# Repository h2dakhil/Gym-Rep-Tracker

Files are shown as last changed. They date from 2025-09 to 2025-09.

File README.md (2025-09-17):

# Fitness Rep Tracker 🏋️‍♂️

A **wrist-mounted STM32 wearable** that detects and classifies **4+ gym exercises** with real-time feedback.  
The project was built completely from scratch, including **custom 4-layer PCB design, embedded firmware, IMU motion sensing, and OLED feedback display.**

---

## 🚀 Features
- **Hardware**
  - Custom **4-layer PCB** designed in KiCad
  - MCU: **STM32F103**
  - IMU: **MPU-6050** (3-axis accelerometer + 3-axis gyroscope, I²C)
  - Display: **SSD1306 OLED** (128×64, I²C)
  - Power: **MCP73831 Li-ion charger**, 3.3 V LDO, battery-sense divider, USB-C input
  - Debug: **SWD header**, status LEDs

- **Firmware (C)**
  - Written in **C** using **PlatformIO** and STM32 HAL drivers
  - **IMU data acquisition** and calibration
  - **Rep detection algorithm** using peak prominence + refractory period filtering
  - Rolling buffer statistics & low-pass signal filters
  - State machine: boot → exercise selection → calibration → running
  - **OLED driver** for real-time rep count & status display
  - UART logging for debugging
  - Peripheral initialization with fallback & error handling

- **Testing & Debugging**
  - SMT soldered & validated using **DMM** and **oscilloscope**
  - Verified stable 3.3 V rail and signal nets

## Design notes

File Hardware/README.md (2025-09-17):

# Gym Rep Tracker Hardware

This directory contains the **hardware design files** for the Gym Rep Tracker, including schematics, PCB layouts, fabrication outputs, and backups.  
The hardware is built around the **STM32F103CBT6 microcontroller**, with supporting circuitry for the **MPU-6050 IMU**, **SSD1306 OLED**, battery charging, and power regulation.

---

## Directory Structure

- **Backups/**  
  Contains backup copies of hardware design files for recovery and version tracking.  

- **Fab/**  
  Fabrication-ready outputs, including Gerber files, drill files, and pick-and-place exports for PCB manufacturing.  

- **PCB/**  
  Source PCB design files (e.g., KiCad project files, layout, footprints).  
  - Includes board layout for the 4-layer stack-up (GND plane, power plane, signal layers).  

- **Schematic/**  
  Electrical schematics showing MCU, IMU, OLED, power management (MCP73831 Li-ion charger, LDO regulator), and supporting passives.  

- **README.md**  
  This file, describing the structure and usage of the hardware directory.  

---

## Usage

1. **View Schematics**  
   Open the files in the `Schematic/` folder using KiCad (recommended version noted in project files).  

2. **Edit PCB Layout**  
   Open the project in KiCad from the `PCB/` folder.  

3. **Generate Manufacturing Files**  
   Use KiCad’s *Plot* and *Fabrication Outputs* to regenerate Gerbers if changes are made.  
   Fabrication-ready files are already available in the `Fab/` folder.  

---

## Notes
- **Backups** are not guaranteed to be the latest version. Always check the active `PCB/` and `Schematic/` folders first.  
- Ensure fabrication files match the correct **4-layer stack-up** before sending to a manufacturer.  
- If modifying, confirm footprints and net connections pass ERC/DRC in KiCad before fabrication.

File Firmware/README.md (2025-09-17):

# Gym Rep Tracker Firmware

This directory contains the embedded firmware for a wrist-mounted rep tracker built around an **STM32F103CBT6 microcontroller**, **MPU-6050 IMU**, and **SSD1306 OLED display**.  
The firmware implements sensor drivers, signal filtering, calibration, and a rep-detection algorithm tailored to multiple exercises.

---

## Features
- **Multi-Exercise Support**: Bicep Curl, Shoulder Press, Bench Press (extendable to more)
- **State Machine Control**: Boot → Exercise Selection → Calibration → Detecting → Running
- **Exercise-Specific Calibration**: Per-exercise baseline mean/std. deviation, with dynamic thresholds
- **Rep Detection Algorithm**: Peak detection with prominence & refractory checks to prevent false counts
- **Low-Pass Filtering**: Smooths accelerometer/gyroscope signals for robust detection
- **OLED UI**: Displays splash, exercise selection, calibration state, rep counts, and status messages
- **UART Debug Logging (optional)**: Real-time streaming of thresholds, IMU samples, and rep detection results
- **Fallback Protection**: I²C bus initialization with automatic downgrade from fast to standard mode if needed

---

## Build & Flash Instructions
1. **Install PlatformIO**: Install the PlatformIO extension in VS Code.  
2. **Open Project**: Open the `Firmware/` directory.  
3. **Build**:  
   platformio run

or click the Build checkmark in the toolbar.

4. Flash: Upload to STM32F103CBT6 via ST-Link:

# Wiring Summary
- **MCU**: STM32F103CBT6  
- **IMU (MPU-6050) & OLED (SSD1306)**: Shared I²C1 bus  
  - PB6 → I2C1_SCL  
  - PB7 → I2C1_SDA  
  - Ensure 3.3 V supply and pull-ups (≈4.7kΩ) on SDA/SCL if not onboard  
- **Optional UART Logging**:  
  - PA2 → TX  
  - PA3 → RX  

---

# Firmware Architecture

## Drivers
- **mpu6050.c**: Initializes sensor, configures DLPF, handles calibration, scaling raw IMU data  
- **ssd1306.c**: Minimal OLED driver with ASCII rendering and UI helpers  
- **i2c_bus.c**: HAL wrapper for I²C; includes fallback from Fast Mode to Standard Mode  

## Core Logic
- **imu_filters.c**: Applies low-pass filters, projects motion onto exercise-specific axes  
- **rep_detect.c**: Maintains rolling mean/std. deviation buffer; detects peaks using thresholds  
- **app_controller.c**: High-level state machine managing boot, calibration, detection, and UI updates  
- **systick.c**: Millisecond tick counter for scheduling  

## UI
- Displays splash, exercise name, calibration, live rep counts  
- Text rendering with auto-centering and truncation  

---

# Adding a New Exercise
1. Add a new entry in `include/exercise_config.h` with thresholds & refractory time.  
2. Implement signal projection in `imu_filters.c`.  
3. Update `app_controller.c` for name display and calibration needs.  
4. Test & tune thresholds using UART logging.  

---

# Debug & Troubleshooting

## Enable Debug Mode
- Define `ENABLE_LOG_UART` in `app_config.h` to stream real-time values at **115200 baud**.  

## Common Issues
- **No reps detected** → lower `thresh_k` or `min_prominence_g`  
- **False positives** → increase `min_prominence_g` or `refractory_ms`  
- **IMU not responding** → check I²C wiring & power  
- **Display issues** → confirm pull-ups on SDA/SCL

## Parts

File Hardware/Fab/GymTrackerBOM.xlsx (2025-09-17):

BOM: Gym Rep Tracker Device
Haya Dakhil
Designator | Description | Quantity | Value | Package/ Footprint | Manufacturer Part Number (MPN) | Supplier | Supplier part number | Link
J1 | Battery Connector | 1 |  | JST_PH_S2B-PH-SM4-TB_1x02-1MP_P2.00mm_Horizontal | S2B-PH-SM4-TB(LF)(SN) | LCSC | C295747 | https://www.lcsc.com/product-detail/C295747.html?s_z=n_JST%20S2B-PH-SM4-TB%28LF%29%28SN%29
J2 | Female OLED Conn | 1 |  | Connector_PinSocket_2.54mm:PinSocket_1x04_P2.54mm_Vertical | BOOMELE(Boom Precision Elec) 2.54-1*4P | LCSC | C2718488 | https://www.lcsc.com/product-detail/C2718488.html
DNP | Male OLED Pin | 1 |  |  | B-2100S04P-A110 | LCSC | C124378 | https://www.lcsc.com/product-detail/C124378.html?s_z=n_C124378
DNP | OLED Display | 1 |  |  | HS91L02W2C01 | LCSC | C5248081 | https://www.lcsc.com/product-detail/C5248081.html?s_z=n_C5248081
DNP | IMU Breakout Board | 1 |  |  |  | Amazon |  | https://www.amazon.ca/Acceleration-Sensors-Accelerometer-Three-Axis-Quadcopter/dp/B0C3LG1Y6W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
J3 | Female IMU Connector | 1 |  | Connector_PinSocket_2.54mm:PinSocket_1x08_P2.54mm_Vertical | 2.54-1*8P | LCSC | C27438 | https://www.lcsc.com/product-detail/C27438.html?s_z=n_1x8%25202.54mm
J4 | USBC Connector | 1 |  | Connector_USB:USB_C_Receptacle_HRO_TYPE-C-31-M-12 | TYPE-C-31-M-12 | LCSC | C165948 | https://www.lcsc.com/product-detail/C165948.html
J5 | SWD Header | 1 |  | Connector_PinHeader_2.54mm:PinHeader_1x05_P2.54mm_Vertical | PH2.54-1X5P-H25 | LCSC | C42431835 | https://www.lcsc.com/product-detail/C42431835.html?s_z=n_1x5%25202.54mm%2520pitch
DNP | SWD Linker | 1 |  |  |  |  |  | https://www.amazon.ca/DAOKAI-Downloader-Programmer-STM8STM32-Programming/dp/B09WVQNFNM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
DNP | Adapter USB-A to C | 1 |  |  |  |  |  | https://www.amazon.ca/Female-Adapter-Charger-Airpods-Samsung/dp/B083GMF4PR?sp_csd=d2lkZ2V0TmFtZT1zcF9hdGY
DNP | Battery | 1 |  |  |  |  |  | https://www.amazon.ca/FITHOOD-Rechargeable-Connector-Household-Appliances/dp/B0CYGN1627
U1 | PMIC | 1 |  | Package_TO_SOT_SMD:SOT-23-5 MIC5504-3.3YM5-TR | MCP73831T-2ACI/OT | LCSC | C424093 | https://www.lcsc.com/product-detail/C424093.html?s_z=n_C424093
U2 | LDO | 1 |  | Package_TO_SOT_SMD:SOT-23-5 | MIC5504-3.3YM5-TR | LCSC | C88419 | https://www.lcsc.com/product-detail/C88419.html?s_z=n_C88419
U3 | STM32 MCU | 1 |  | Package_QFP:LQFP-48_7x7mm_P0.5mm | STM32F103C8T6 | LCSC | C8734 | https://www.lcsc.com/product-detail/C8734.html?s_z=n_STM32F103C8T6
D1, D3 | Green LED | 2 |  | LED_SMD:LED_0603_1608Metric_Pad1.05x0.95mm_HandSolder | A-SP192DGHC-C01-4T | LCSC | C19171301 | https://www.lcsc.com/product-detail/C19171301.html?s_z=n_green%20led
D2 | TVS Diode | 1 |  | Diode_SMD:D_SMF | SMF5.0A | LCSC | C151296 | https://www.lcsc.com/product-detail/C151296.html?s_z=n_SMF5.0A
D4 | Yellow LED | 1 |  | LED_SMD:LED_0603_1608Metric_Pad1.05x0.95mm_HandSolder | XL-1608UYC-06 | LCSC | C965802 | https://www.lcsc.com/product-detail/C965802.html?s_z=n_yellow%20led
FB1 | Ferrite Bead | 1 |  | Resistor_SMD:R_0603_1608Metric | BLM18PG121SN1D | LCSC | C14709 | https://www.lcsc.com/product-detail/C14709.html?s_z=n_ferrite%2520bead
R1, R6 |  | 2 | 5.1k | Resistor_SMD:R_0603_1608Metric | RC0603FR-075K1L | LCSC | C105580 | https://www.lcsc.com/product-detail/C105580.html?s_z=n_5.1k%2520r
R2 |  | 1 | 470 | Resistor_SMD:R_0603_1608Metric | RC0603FR-07470RL | LCSC | C114669 | https://www.lcsc.com/product-detail/C114669.html?s_z=n_470%2520ohm%2520r
R3 |  | 1 | 2.0k | Resistor_SMD:R_0603_1608Metric | FRC0603J202 TS | LCSC | C2907137 | https://www.lcsc.com/product-detail/C2907137.html?s_z=n_2k%2520resistor%2520
R4, R5 |  | 2 | 10k | Resistor_SMD:R_0603_1608Metric | RC0603FR-0710KL | LCSC | C98220 | https://www.lcsc.com/product-detail/C98220.html?s_z=n_10k%2520resistor
R7, R8 |  | 2 | 1k | Resistor_SMD:R_0603_1608Metric | RC0603FR-071KL | LCSC | C22548 | https://www.lcsc.com/product-detail/C22548.html?s_z=n_1kohm%2520resistor
R9 |  | 1 | 100k | Resistor_SMD:R_0603_1608Metric | RC0603FR-07100KL | LCSC | C14675 | https://www.lcsc.com/product-detail/C14675.html?s_z=n_100kohm%2520resistor
R10 |  | 1 | 240k | Resistor_SMD:R_1206_3216Metric | FRC1206F2403TS | LCSC | C2907378 | https://www.lcsc.com/product-detail/C2907378.html?s_z=n_240kohm%2520resistor
C1 |  | 1 | 10uF | Capacitor_SMD:C_0805_2012Metric_Pad1.18x1.45mm_HandSolder | 0805X5R106K500NT | LCSC | C48579582 | https://www.lcsc.com/product-detail/C48579582.html?s_z=n_10uF%2520capacitor
C2, C3, C4, C10, C12 |  | 5 | 4.7uF | Capacitor_SMD:C_0603_1608Metric | CC0603KRX5R6BB475 | LCSC | C109456 | https://www.lcsc.com/product-detail/C109456.html?s_z=n_4.7uf%2520capacitor%2520yageo
C5, C6 |  | 2 | 1uF | Capacitor_SMD:C_0603_1608Metric_Pad1.08x0.95mm_HandSolder | CC0603KRX7R9BB105 | LCSC | C559769 | https://www.lcsc.com/product-detail/C559769.html?s_z=n_1uF%2520capacitor%2520yageo
C7, C8, C9, C11, C13, C14, C15, C16, C17 |  | 9 | 0.1uF | Capacitor_SMD:C_0603_1608Metric_Pad1.08x0.95mm_HandSolder |  | LCSC | C14663 | https://www.lcsc.com/product-detail/C14663.html?s_z=n_0.1uF%2520capacitor
SW1 | Start Button | 1 |  | Button_Switch_SMD:SW_SPST_TL3305A | TS-1187A-C-E-B | LCSC | C318887 | https://www.lcsc.com/product-detail/C318887.html
 | Helping hands |  |  |  |  |  |  | https://www.amazon.ca/STANZ-Magnifying-Selected-Soldering-Electronics/dp/B016C8RWQI
 | Flux |  |  |  |  |  |  | https://www.amazon.ca/TOWOT-Rosin-Solder-Paste-Soldering/dp/B0CNVM1KRT?sp_csd=d2lkZ2V0TmFtZT1zcF9hdGY
 | Wick |  |  |  |  |  |  | https://www.amazon.ca/Solder-TOWOT-Desoldering-Wicks-SW-2530/dp/B0943PDCC4?sp_csd=d2lkZ2V0TmFtZT1zcF9hdGY

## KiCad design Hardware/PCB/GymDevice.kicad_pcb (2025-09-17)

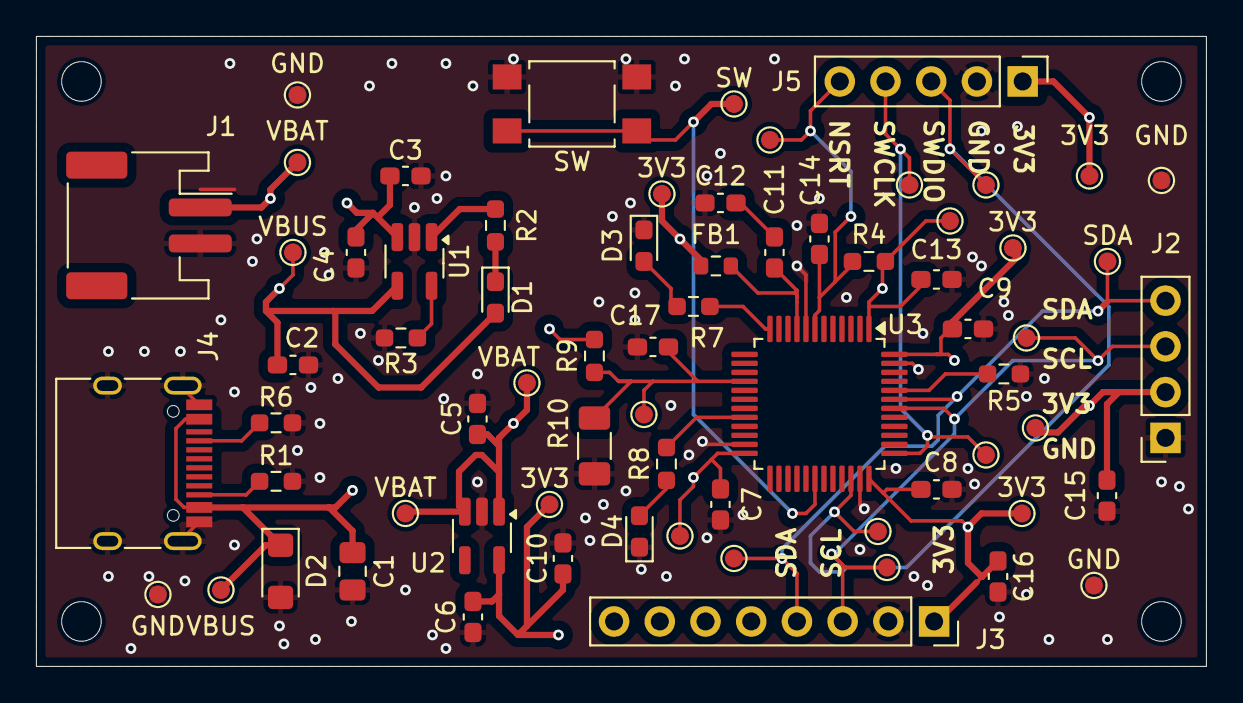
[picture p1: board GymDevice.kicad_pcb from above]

Board: 4 copper layers, 65.0 x 35.0 mm, 57 parts (0 on the bottom side), 23 nets.

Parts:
3V3, 3V3#2, 3V3#3, 3V3#4, 3V3#5: TestPoint_Pad_D1.0mm
 VBAT: TestPoint_Pad_D1.0mm
C1: 10uF; C_0805_2012Metric_Pad1.18x1.45mm_HandSolder
C2, C3, C4, C10, C12: 4.7uF; C_0603_1608Metric_Pad1.08x0.95mm_HandSolder
C5, C6: 1uF; C_0603_1608Metric_Pad1.08x0.95mm_HandSolder
C7, C8, C9, C11, C13, C14, C15, C16, C17: 0.1uF; C_0603_1608Metric_Pad1.08x0.95mm_HandSolder
D1, D3, D4: LED; LED_0603_1608Metric_Pad1.05x0.95mm_HandSolder
D2: TVS; D_SMF
FB1: FerriteBead_Small; R_0603_1608Metric
GND: TestPoint_Pad_D1.0mm
GND#2, GND#3, GND#4: TestPoint_Pad_D1.0mm
J1: JST S2B-PH-SM4-TB(LF)(SN); JST_PH_S2B-PH-SM4-TB_1x02-1MP_P2.00mm_Horizontal
J2: SSD1306 I2C 128x32 OLED Module; PinSocket_1x04_P2.54mm_Vertical
J3: IMU Breakout Board; PinSocket_1x08_P2.54mm_Vertical
J4: USB_C_Receptacle_USB2.0_16P; USB_C_Receptacle_HRO_TYPE-C-31-M-12
J5: ST-Link; PinHeader_1x05_P2.54mm_Vertical
R1, R6: 5.1k; R_0603_1608Metric_Pad0.98x0.95mm_HandSolder
R2: 470; R_0603_1608Metric_Pad0.98x0.95mm_HandSolder
R3: 2k; R_0603_1608Metric_Pad0.98x0.95mm_HandSolder
R4, R5: 10k; R_0603_1608Metric_Pad0.98x0.95mm_HandSolder
R7, R8: 1k; R_0603_1608Metric_Pad0.98x0.95mm_HandSolder
R9: 100k; R_0603_1608Metric_Pad0.98x0.95mm_HandSolder
R10: 240k; R_1206_3216Metric_Pad1.30x1.75mm_HandSolder
SDA: TestPoint_Pad_D1.0mm
SW: TestPoint_Pad_D1.0mm
SW#2: SW_Push; SW_SPST_TL3305A
U1: MCP73831-2-OT; SOT-23-5_HandSoldering
U2: MIC5504-3.3YM5; SOT-23-5_HandSoldering
U3: STM32F103C8Tx; LQFP-48_7x7mm_P0.5mm
VBAT: TestPoint_Pad_D1.0mm
VBAT#2: TestPoint_Pad_D1.0mm
VBUS: TestPoint_Pad_D1.0mm
VBUS#2: TestPoint_Pad_D1.0mm

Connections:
/3V3: 3V3.1, 3V3#2.1, 3V3#3.1, 3V3#4.1, 3V3#5.1, C6.1, C7.1, C8.2, C9.1, C10.1, C13.2, C15.1, C16.1, FB1.2, J2.2, J3.1, J5.1, R4.1, U2.5 (VOUT), U3.1 (VBAT), U3.24 (VDD), U3.36 (VDD), U3.48 (VDD)
/NSRT: C14.1, J5.5, R4.2, U3.7 (NRST)
/SCL: J2.3, J3.3, U3.42 (PB6)
/SDA: J2.4, J3.4, SDA.1, U3.43 (PB7)
/SWCLK: J5.4, U3.37 (PA14)
/SWDIO: J5.3, U3.34 (PA13)
/VBAT: VBAT.1, C3.1, C4.1, C5.1, J1.1, R9.1, U1.3 (V_{BAT}), U2.1 (VIN), U2.3 (EN), VBAT.1, VBAT#2.1
/VBAT_SENSE: C17.1, R9.2, R10.1, U3.16 (PA6)
/VBUS: C1.2, C2.2, D1.2 (A), D2.1 (K), J4.A4 (VBUS), J4.A9 (VBUS), J4.B4 (VBUS), J4.B9 (VBUS), U1.4 (V_{DD}), VBUS.1, VBUS#2.1
GND: C1.1, C2.1, C3.2, C4.2, C5.2, C6.2, C7.2, C8.1, C9.2, C10.2, C12.2, C13.1, C14.2, C15.2, C16.2, C17.2, D2.2 (A), D3.1 (K), D4.1 (K), GND.1, GND#2.1, GND#3.1, GND#4.1, J1.2, J2.1, J3.2, J4.A1 (GND), J4.A12 (GND), J4.B1 (GND), J4.B12 (GND), J4.S1 (SHIELD), J5.2, R1.2, R3.2, R5.1, R6.2, R10.2, SW#2.2, U1.2 (V_{SS}), U2.2 (GND), U3.8 (VSSA), U3.23 (VSS), U3.35 (VSS), U3.47 (VSS)
unnamed: C11.2, C12.1
unnamed: D1.1 (K), R2.1
unnamed: D3.2 (A), R7.2
unnamed: D4.2 (A), R8.2
unnamed: J4.A5 (CC1), R6.1
unnamed: J4.B5 (CC2), R1.1
unnamed: R3.1, U1.5 (PROG)
unnamed: R2.2, U1.1 (STAT)
unnamed: R5.2, U3.44 (BOOT0)
unnamed: R7.1, U3.12 (PA2)
unnamed: SW#2.1, U3.30 (PA9)
unnamed: R8.1, U3.20 (PB2)
unnamed: C11.1, FB1.1, U3.9 (VDDA)

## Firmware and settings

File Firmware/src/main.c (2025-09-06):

#include "main.h"
#include "stm32f1xx_hal.h"
#include "app_config.h"
#include "mcu_pinmap.h"
#include "i2c_bus.h"
#include "mpu6050.h"
#include "ssd1306.h"
#include "systick.h"
#include "log_uart.h"
#include "app_controller.h"
#include "exercise_config.h"

// Global HAL handles
I2C_HandleTypeDef hi2c1;
#ifdef ENABLE_LOG_UART
UART_HandleTypeDef huart2;
#endif

// Function prototypes
static void SystemClock_Config(void);
static void GPIO_Init(void);

/**
 * @brief Main function.
 */
int main(void)
{
    // HAL initialization
    HAL_Init();
    
    // Configure system clock
    SystemClock_Config();
    
    // Initialize GPIO
    GPIO_Init();
    
    // Initialize I2C bus
    if (i2c_bus_init() != HAL_OK)
    {
        Error_Handler();
    }
    
#ifdef ENABLE_LOG_UART
    // Initialize optional UART logging
    log_uart_init();
#endif
    
    // Initialize MPU-6050
    if (mpu6050_init() != HAL_OK)
    {
        Error_Handler();
    }
    
    // Initialize SSD1306 OLED
    if (ssd1306_init() != HAL_OK)
    {
        Error_Handler();
    }
    
    // Initialize system tick
    systick_init();
    
    // Initialize application controller
    app_controller_init();
    
    // Main application loop
    while (1)
    {
        app_controller_loop();
        
        // Small delay to prevent tight loop
        HAL_Delay(1);
    }
}

/**
 * @brief Configures the system clock to 72 MHz.
 */
static void SystemClock_Config(void)
{
    RCC_OscInitTypeDef RCC_OscInitStruct = {0};
    RCC_ClkInitTypeDef RCC_ClkInitStruct = {0};

    // Configure the main internal regulator output voltage
    // Note: STM32F1 doesn't have PWREx functions, so we skip this step

    // Initializes the RCC Oscillators according to the specified parameters
    RCC_OscInitStruct.OscillatorType = RCC_OSCILLATORTYPE_HSE;
    RCC_OscInitStruct.HSEState = RCC_HSE_ON;
    RCC_OscInitStruct.HSEPredivValue = RCC_HSE_PREDIV_DIV1;
    RCC_OscInitStruct.HSIState = RCC_HSI_ON;
    RCC_OscInitStruct.PLL.PLLState = RCC_PLL_ON;
    RCC_OscInitStruct.PLL.PLLSource = RCC_PLLSOURCE_HSE;
    RCC_OscInitStruct.PLL.PLLMUL = RCC_PLL_MUL9;
    if (HAL_RCC_OscConfig(&RCC_OscInitStruct) != HAL_OK)
    {
        Error_Handler();
    }

    // Initializes the CPU, AHB and APB buses clocks
    RCC_ClkInitStruct.ClockType = RCC_CLOCKTYPE_HCLK|RCC_CLOCKTYPE_SYSCLK
                                |RCC_CLOCKTYPE_PCLK1|RCC_CLOCKTYPE_PCLK2;
    RCC_ClkInitStruct.SYSCLKSource = RCC_SYSCLKSOURCE_PLLCLK;
    RCC_ClkInitStruct.AHBCLKDivider = RCC_SYSCLK_DIV1;
    RCC_ClkInitStruct.APB1CLKDivider = RCC_HCLK_DIV2;
    RCC_ClkInitStruct.APB2CLKDivider = RCC_HCLK_DIV1;

    if (HAL_RCC_ClockConfig(&RCC_ClkInitStruct, FLASH_LATENCY_2) != HAL_OK)
    {
        Error_Handler();
    }
}

/**
 * @brief Initializes GPIO pins.
 */
static void GPIO_Init(void)
{
    GPIO_InitTypeDef GPIO_InitStruct = {0};

    // Enable GPIO clocks
    __HAL_RCC_GPIOA_CLK_ENABLE();
    __HAL_RCC_GPIOB_CLK_ENABLE();

    // Configure I2C1 pins (PB6=SCL, PB7=SDA)
    GPIO_InitStruct.Pin = I2C1_SCL_PIN | I2C1_SDA_PIN;
    GPIO_InitStruct.Mode = GPIO_MODE_AF_OD;
    GPIO_InitStruct.Pull = GPIO_PULLUP;
    GPIO_InitStruct.Speed = GPIO_SPEED_FREQ_HIGH;
    HAL_GPIO_Init(I2C1_SCL_GPIO_PORT, &GPIO_InitStruct);

#ifdef ENABLE_LOG_UART
    // Configure UART2 pins (PA2=TX, PA3=RX)
    GPIO_InitStruct.Pin = UART2_TX_PIN | UART2_RX_PIN;
    GPIO_InitStruct.Mode = GPIO_MODE_AF_PP;
    GPIO_InitStruct.Pull = GPIO_NOPULL;
    GPIO_InitStruct.Speed = GPIO_SPEED_FREQ_HIGH;
    HAL_GPIO_Init(UART2_TX_GPIO_PORT, &GPIO_InitStruct);
#endif
}

/**
 * @brief Error handler function.
 */
void Error_Handler(void)
{
    // User can add his own implementation to report the HAL error return state
    __disable_irq();
    while (1)
    {
        // Error occurred, halt execution
    }
}

#ifdef USE_FULL_ASSERT
/**
 * @brief Reports the name of the source file and the source line number
 * where the assert_param error has occurred.
 */
void assert_failed(uint8_t *file, uint32_t line)
{
    // User can add his own implementation to report the file name and line number
    // ex: printf("Wrong parameters value: file %s on line %d\r\n", file, line)
}
#endif

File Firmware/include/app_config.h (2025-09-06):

#ifndef APP_CONFIG_H
#define APP_CONFIG_H

// IMU Configuration
#define IMU_SAMPLE_HZ 200  // IMU sampling frequency in Hz

// Display Configuration
#define OLED_WIDTH 128
#define OLED_HEIGHT 64

// Timing Configuration
#define UI_UPDATE_RATE_HZ 10  // UI update rate in Hz
#define IMU_READ_INTERVAL_MS (1000 / IMU_SAMPLE_HZ)  // Time between IMU reads
#define IMU_SAMPLE_INTERVAL_MS IMU_READ_INTERVAL_MS  // Alias for compatibility
#define UI_REFRESH_INTERVAL_MS (1000 / UI_UPDATE_RATE_HZ)  // UI refresh interval

// Exercise Detection Configuration
#define CALIBRATION_SAMPLES 100  // Number of samples to collect during calibration
#define DETECTION_WARMUP_MS 1000  // Warm-up time before detection starts

// Logging Configuration
#define ENABLE_LOG_UART 0  // Enable/disable UART logging

#endif // APP_CONFIG_H

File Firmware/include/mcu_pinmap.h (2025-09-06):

#ifndef MCU_PINMAP_H
#define MCU_PINMAP_H

#include "stm32f1xx_hal.h"

// TODO: Adjust I2C and UART pin assignments if your PCB differs.
// The following assignments are common for STM32F103CB.

// I2C1 Pins
#define I2C1_SCL_PIN        GPIO_PIN_6
#define I2C1_SCL_GPIO_PORT  GPIOB
#define I2C1_SDA_PIN        GPIO_PIN_7
#define I2C1_SDA_GPIO_PORT  GPIOB

extern I2C_HandleTypeDef hi2c1;

// Optional UART2 Pins for logging
#ifdef ENABLE_LOG_UART
#define UART2_TX_PIN        GPIO_PIN_2
#define UART2_TX_GPIO_PORT  GPIOA
#define UART2_RX_PIN        GPIO_PIN_3
#define UART2_RX_GPIO_PORT  GPIOA

extern UART_HandleTypeDef huart2;
#endif /* ENABLE_LOG_UART */

#endif // MCU_PINMAP_H
